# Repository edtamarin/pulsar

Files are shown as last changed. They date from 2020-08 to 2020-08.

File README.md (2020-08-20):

# pulsar
Line Follower robot for the 2017 RobotChallenge.

## Hardware
### Chassis
The body of the robot is a custom-made PCB. In hindsight, this added more weight to the overall design. The PCB was designed in EagleCAD.
### Wheels
To increase traction, the wheels were custom-made. The rims were 3D printed to be wide for more grip. The tyres were made from a silicone tube to increase grip on the surface.

## Code
The code is very simple. This design does not use a PID, however it would benefit from one. 

The array of sensors was placed in the front of the robot. The algorithm calculates the deviation from the straight line and runs the motors accordingly.

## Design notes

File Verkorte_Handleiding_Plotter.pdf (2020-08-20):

# PCB Maken

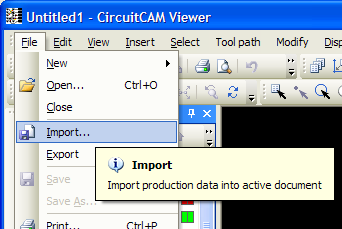
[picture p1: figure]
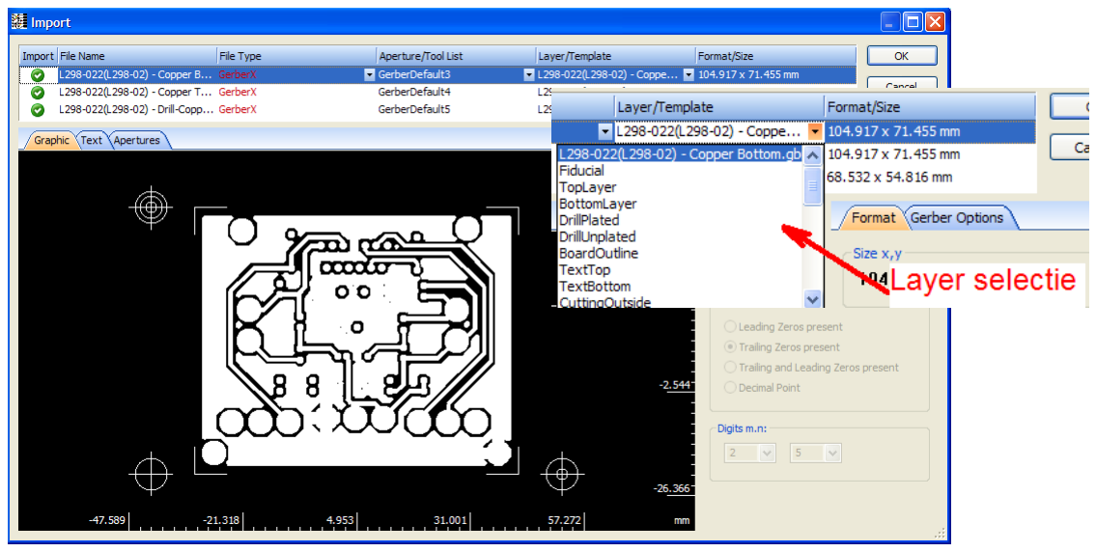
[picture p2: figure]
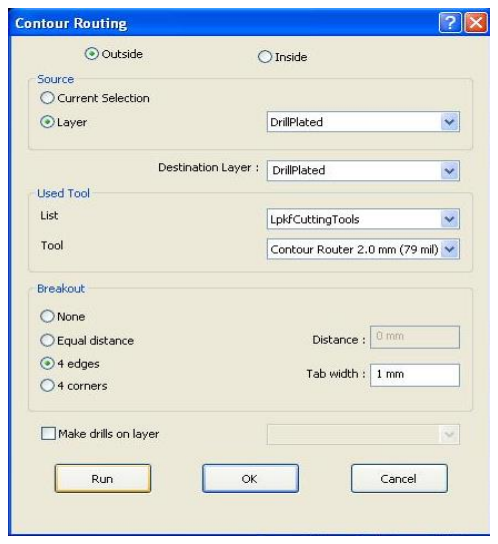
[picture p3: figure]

Samengesteld door A.Yüksel | versie 2016 | 1
A. CircuitCam
B. Boardmaster

blad 1
blad 2

Voordat er een print gefreest kan worden hebben we 2 bestanden voor enkelzijdig print en drie bestanden voor dubbelzijdige print nodig. Deze bestanden worden door het layout programma gecreëerd en zijn van het type Gerber 274X.

A. CircuitCam
- Start CircuitCam
- Ga naar File en Inport
- Selecteer de bestanden: Voor enkelzijdige print Botom Layer en Drill layer
Voor dubbelzijdige print Top layer, Botom Layer en Drill layer
- De geselecteerde bestanden worden in een nieuw menu getoond: geef hier, voor elk bestandn, de layer aan en
druk dan OK.
- Selecteer ongewenste lijnen en verwijder deze zodat alleen de te frezen gebied over blijft.
- | Klik op het icoontje | en selecteer de te frezen gebied. Klik nu op het icoontje | .
- | Selecteer weer het hele lay-out en klik op het | icoontje.
- Geef in het te voorschijn gekomen menu de volgende instelling in als het

plaatje hier naast. Deze instellingen zijn voor het uitsnijden van de print.

| Klik daarna op “Run”.
- Start BoardMaster op en ga terug naar CircuitCam.
- | Klik op het | icoontje en het lay-out is naar BoardMaster
| getransformeerd.

# PCB Maken

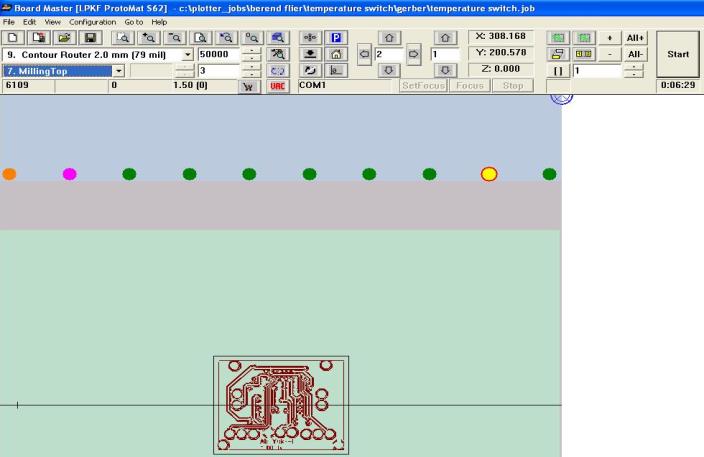
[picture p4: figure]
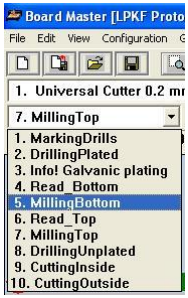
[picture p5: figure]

Samengesteld door A.Yüksel | versie 2016 | 2
B. Boardmaster
- Ga naar BoardMaster.
- Het Lay-out staat nu in het midden. Je kunt lay-out op elk gewenste plek zetten als je wilt.
- | Klik op het | icoontje en selecteer het lay-out. Versleep het laya-out naar de gewenste plek.
- Met de onderstaande iconen kan de spinder verplaatst worden naar elk gewenste plaats.
- Selecteer nu als eerst MillingTop job uit de Job-menu, zie hier naast en klik op het All+ icoontje en vervolgens op het Start icoontje. De machine begint met frezen.
- | Als het frezen van de bovenkant klaar is klik op het | icoontje zodat de

spindel naar de pauze stand gaat.

- Draai nu de print horizontaal om zodat de onderkant gefreesd kan worden.
- Selecteer MillingBottom job. Klik op het All+ icoontje en vervolgens op het

Start icoontje. De machine begint met frezen.

- Als het frezen van de onderkant klaar is parkeer de spindel door op

icoon te klikken.

- Draai de printplaat van voor naar achteren.
- Selecteer DrillingPlated job. Klik op het All+ icoontje en vervolgens op het Start icoontje. De machine

begint met boren. (Omdat we in CircuitCam de CuttingOutside job in de DrillingPlated job hebben

ingesteld zal het uitsnijden ook in dit job gebeuren).

- | De print is nu klaar. Klik op het | icoontje zodat de spindel naar de pauze stand gaat en knip het

printje uit het printplaat.

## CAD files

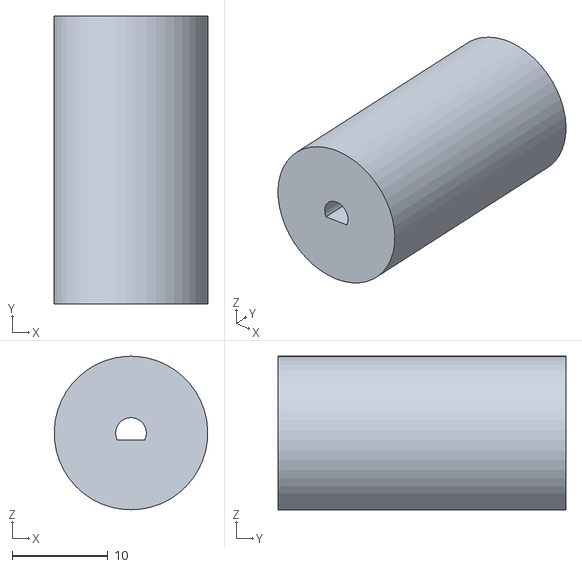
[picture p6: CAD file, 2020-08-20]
Models/Wheel_30.STL
16.0 x 30.0 x 16.0

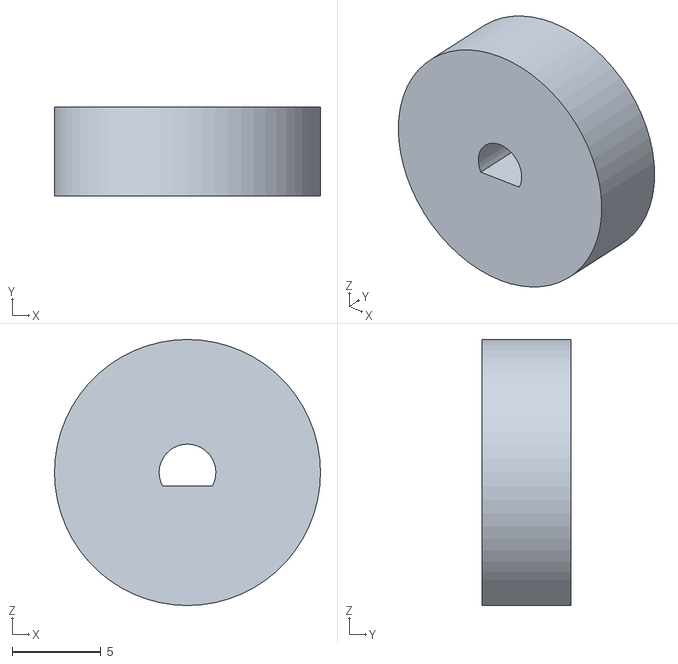
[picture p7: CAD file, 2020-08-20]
Models/Wheel_Test.STL
15.0 x 5.00 x 15.0

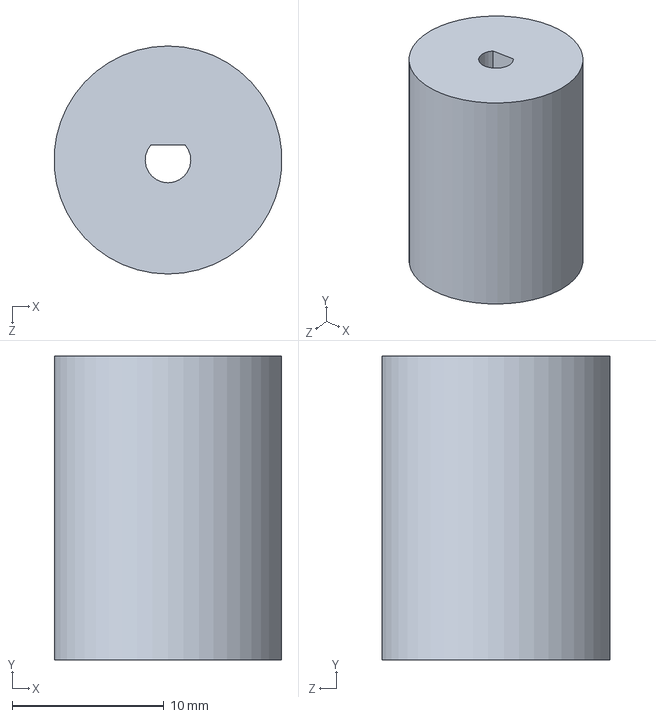
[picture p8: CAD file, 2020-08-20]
Models/Wheel_20.SLDPRT
15.0 x 20.0 x 15.0 mm

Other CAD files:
Models/Wheel.SLDPRT
Models/Wheel_20.STL

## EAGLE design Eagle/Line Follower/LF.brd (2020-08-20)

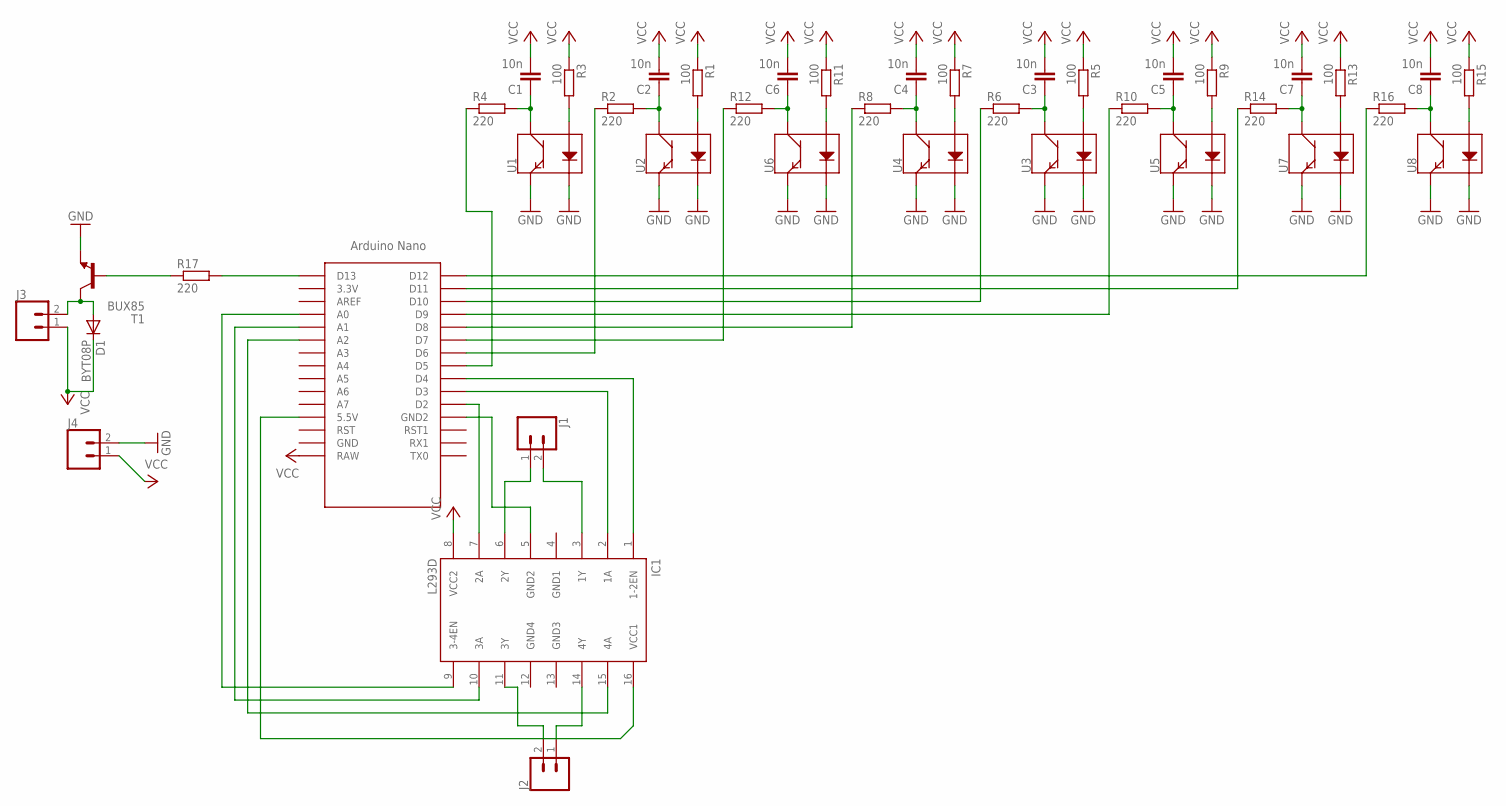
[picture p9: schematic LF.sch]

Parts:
C1, C2, C3, C4, C5, C6, C7, C8: 10n; C0402
D1: BYT08P; TO220ACS
IC1: L293D; DIL16
J1, J2, J3, J4: CONN_02; 1X02
R1, R3, R5, R7, R9, R11, R13, R15: 100; R0402
R2, R4, R6, R8, R10, R12, R14, R16: 220; R0402
R17: 220; R1206
T1: BUX85; TO220
U1, U2, U3, U4, U5, U6, U7, U8: QRE1113SMD-W; QRE1113-W
U$1: NANO

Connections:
GND: J4.2, T1.3 (E), U1.2 (K), U1.4 (E), U2.2 (K), U2.4 (E), U3.2 (K), U3.4 (E), U4.2 (K), U4.4 (E), U5.2 (K), U5.4 (E), U6.2 (K), U6.4 (E), U7.2 (K), U7.4 (E), U8.2 (K), U8.4 (E)
GND1: IC1.4 (GND1)
GND3: IC1.13 (GND3)
GND4: IC1.12 (GND4)
unnamed: R3.2, U1.1 (A)
unnamed: C1.1, R4.2, U1.3 (C)
unnamed: R16.1, U$1.D12
unnamed: R1.2, U2.1 (A)
unnamed: C2.1, R2.2, U2.3 (C)
unnamed: R5.2, U3.1 (A)
unnamed: C3.1, R6.2, U3.3 (C)
unnamed: R7.2, U4.1 (A)
unnamed: C4.1, R8.2, U4.3 (C)
unnamed: R9.2, U5.1 (A)
unnamed: C5.1, R10.2, U5.3 (C)
unnamed: R11.2, U6.1 (A)
unnamed: C6.1, R12.2, U6.3 (C)
unnamed: R13.2, U7.1 (A)
unnamed: C7.1, R14.2, U7.3 (C)
unnamed: R15.2, U8.1 (A)
unnamed: C8.1, R16.2, U8.3 (C)
unnamed: R14.1, U$1.D11
unnamed: R6.1, U$1.D10
unnamed: R10.1, U$1.D9
unnamed: R8.1, U$1.D8
unnamed: R12.1, U$1.D7
unnamed: R2.1, U$1.D6
unnamed: R4.1, U$1.D5
unnamed: IC1.1 (1-2EN), U$1.D4
unnamed: IC1.2 (1A), U$1.D3
unnamed: IC1.7 (2A), U$1.D2
unnamed: IC1.9 (3-4EN), U$1.A0
unnamed: IC1.10 (3A), U$1.A1
unnamed: IC1.15 (4A), U$1.A2
unnamed: IC1.6 (2Y), J1.1
unnamed: IC1.3 (1Y), J1.2
unnamed: IC1.5 (GND2), U$1.GND1 (GND2)
unnamed: IC1.11 (3Y), J2.2
unnamed: IC1.14 (4Y), J2.1
unnamed: IC1.16 (VCC1), U$1.5V (5.5V)
unnamed: R17.2, U$1.D13
unnamed: R17.1, T1.1 (B)
unnamed: D1.A, J3.2, T1.2 (C)
VCC: C1.2, C2.2, C3.2, C4.2, C5.2, C6.2, C7.2, C8.2, D1.C, IC1.8 (VCC2), J3.1, J4.1, R1.1, R3.1, R5.1, R7.1, R9.1, R11.1, R13.1, R15.1, U$1.RAW

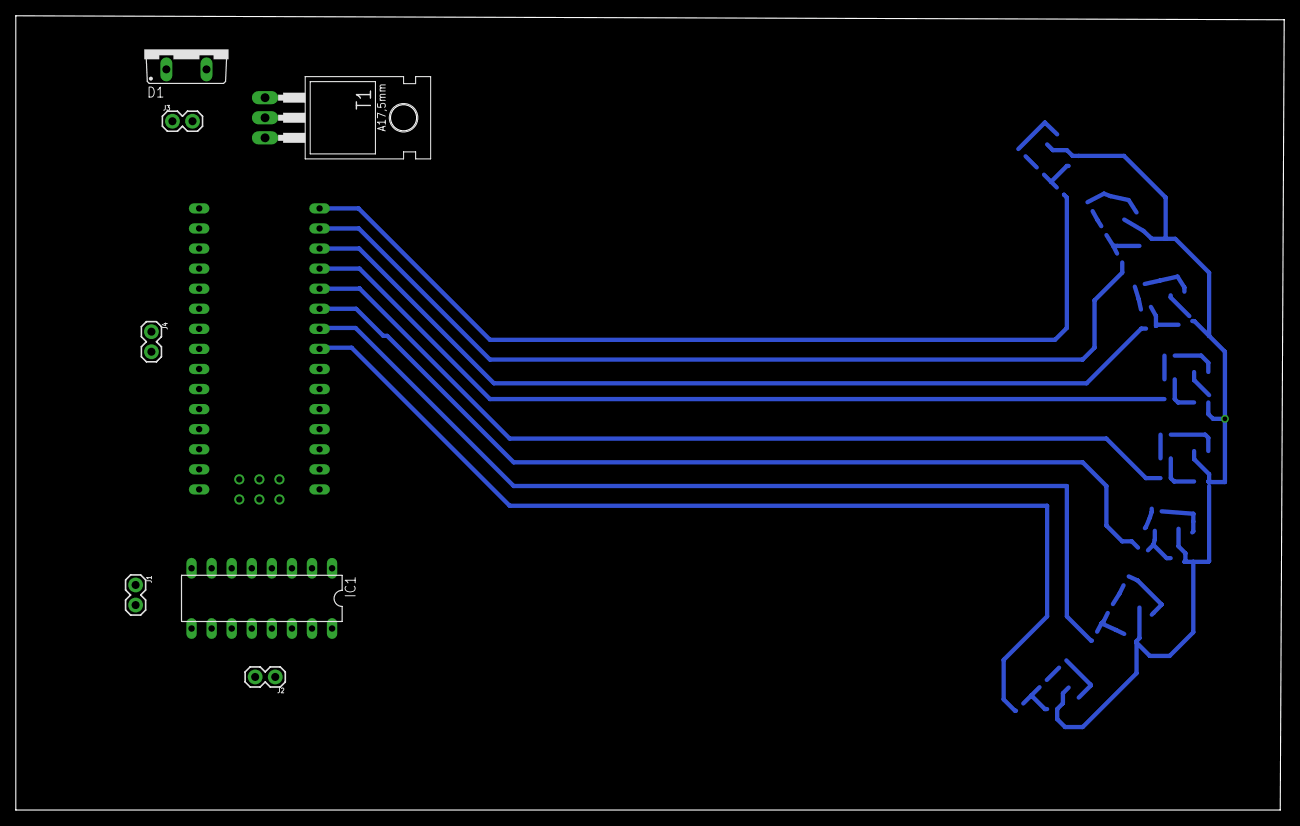
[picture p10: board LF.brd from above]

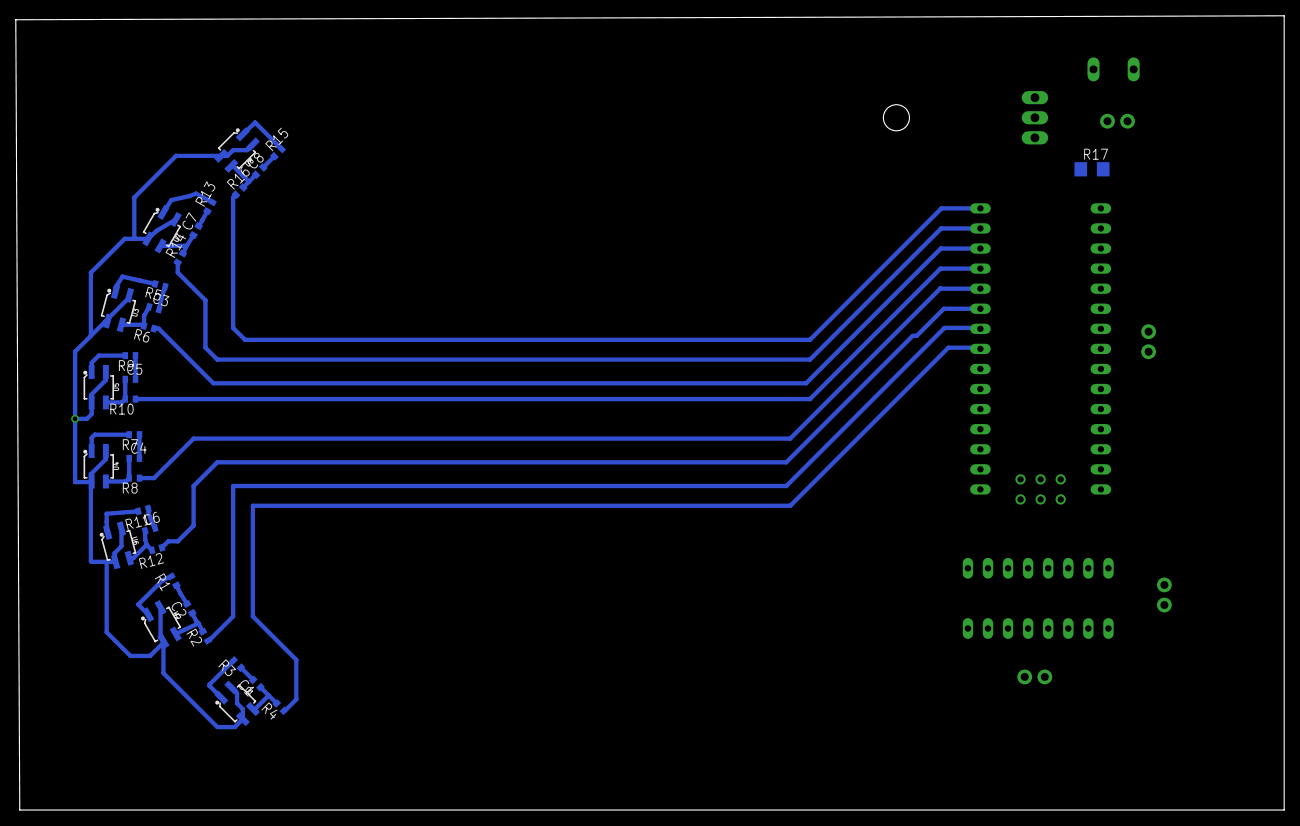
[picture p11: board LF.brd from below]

Board: 2 copper layers, 160.5 x 100.5 mm, 41 parts (33 on the bottom side), 41 nets.

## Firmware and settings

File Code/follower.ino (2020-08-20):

#include <IRremote.h>

bool running = false;
/*
int IR_PIN = A3;
IRrecv irrecv(IR_PIN);
decode_results results;
#define POWER 0x10EFD827 
*/

  // define motor controls
#define E1 PD3  // Enable Pin for motor 1
#define E2 10  // Enable Pin for motor 2
#define I1 4  // Control pin 1 for motor 1
#define I2 2  // Control pin 2 for motor 1
#define I3 A1  // Control pin 1 for motor 2
#define I4 A0  // Control pin 2 for motor 2

int sensorPins[] = {5,6,7,8,9,A5,11,12}; // from right to left
int sensorResult[8];

int max_speed = 255;
float factor = 5.5;
int oldLine;
IRrecv irrecv(A3);
decode_results results;
const uint16_t POWER = 0xD827;
const uint16_t CENTRE = 0x20DF;

void setup() {
  // put your setup code here, to run once:
  Serial.begin(9600);
  //delay(2000);
  irrecv.enableIRIn(); // Start the receiver
}

void loop() {
  int line;
  int rightMotorSpeed;
  int leftMotorSpeed;
  stateSelect(); // check for a signal
  if (running){
    readSensors();
    line = sensorResult[7]+2*sensorResult[6]+3*sensorResult[5]+4*sensorResult[4]+5*sensorResult[3]+6*sensorResult[2]+7*sensorResult[1]+8*sensorResult[0];
    line = 10* line / (sensorResult[7]+sensorResult[6]+sensorResult[5]+sensorResult[4]+sensorResult[3]+sensorResult[2]+sensorResult[1]+sensorResult[0]);
    if (line<=0){
      line = oldLine;
    }
    Serial.println(line);
    if (line<=35){
      moveRobot(max_speed,max_speed,1);
    }else if (line>=55){
      moveRobot(max_speed,max_speed,2);
    }else{
      moveRobot(max_speed,max_speed,0);
    }
     //moveRobot(leftMotorSpeed,rightMotorSpeed,0);
     oldLine = line;
  }else{
    moveRobot(0,0,0); // stop
  }
}

void moveRobot(int speedLeft, int speedRight, int dir){ // moving the robot
  // I use differential steering, speed is important
  analogWrite(E1, speedRight); // right
  analogWrite(E2, speedLeft); // left
      // always go forward
  if (dir == 0){ // forward
    digitalWrite(I1, LOW);
    digitalWrite(I2, HIGH);
    digitalWrite(I3, LOW);
    digitalWrite(I4, HIGH);
  }else if (dir == 1){ // left
    digitalWrite(I1, LOW);
    digitalWrite(I2, HIGH);
    digitalWrite(I3, HIGH);
    digitalWrite(I4, LOW);    
  }else{ // right
    digitalWrite(I1, HIGH);
    digitalWrite(I2, LOW);
    digitalWrite(I3, LOW);
    digitalWrite(I4, HIGH);    
  }

}

void readSensors(){
  for (int i =0; i<8; i++){
    pinMode(sensorPins[i], OUTPUT );
    digitalWrite(sensorPins[i], HIGH );  
    delayMicroseconds(10);
    pinMode(sensorPins[i], INPUT );
    long time = micros();
    //time how long the input is HIGH, but quit after 1ms as nothing happens after that
    while (digitalRead(sensorPins[i]) == HIGH && micros() - time < 125); 
    int diff = micros() - time;
    // if line detected (this usually happens at above 100 us
    if (diff>=100){
      sensorResult[i] = 1;
    }else{
      sensorResult[i] = 0;
    }
  }
}

void stateSelect(){
  if (irrecv.decode(&results)) 
  {
    Serial.println(results.value);
    uint16_t resCode = (results.value & 0xFFFF);
    if (resCode == POWER) 
    {
      running = true;
    }
    if (resCode == CENTRE){
      running = false;
    }
    irrecv.resume();
  }
}

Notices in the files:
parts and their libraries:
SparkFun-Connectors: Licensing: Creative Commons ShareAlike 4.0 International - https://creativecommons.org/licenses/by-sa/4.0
